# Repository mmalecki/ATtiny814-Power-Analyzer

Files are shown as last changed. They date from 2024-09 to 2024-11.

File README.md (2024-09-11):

# Pocker Power Prowler

**Note: this is still very much a work in progress, and next version will bring considerable improvements over the current one.**

Pocket Power Prowler is a tiny programmable constant current dummy load with voltage and current sensors for test device's power supply, as well as its output under test.

It is programmable via USB using a simple text-based protocol, and [in the future](https://github.com/mmalecki/Pocket-Power-Prowler/issues/4)), the [SCPI protocol](https://en.wikipedia.org/wiki/Standard_Commands_for_Programmable_Instruments).

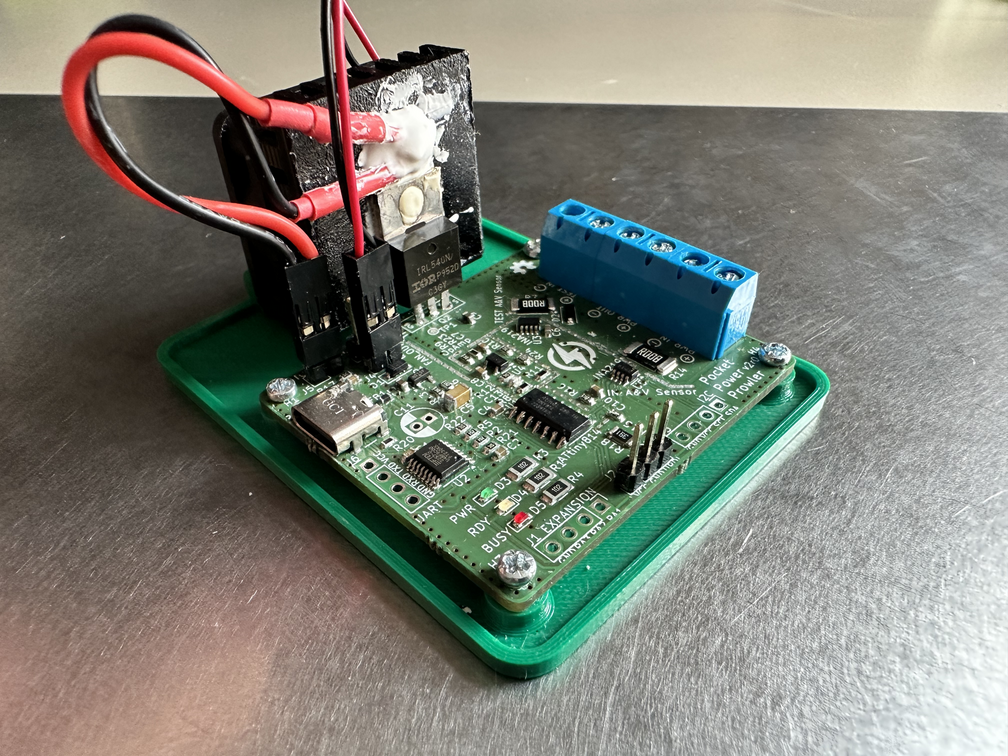
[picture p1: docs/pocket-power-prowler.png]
Pocket Power Prowler picture


It is based on the [ATtiny814 Power Analyzer](https://github.com/wagiminator/ATtiny814-Power-Analyzer) by [@wagiminator](https://github.com/wagiminator/ATtiny814-Power-Analyzer).
If you're interested in how the project changed, check out the [changelog](CHANGELOG.md).

The overarching goal of the project is to create a portable, accurate, reliable and safe dummy load.

# Current control
Current control is implemented using the ATtiny814's digital-to-analog converter (DAC), a level-shifting operational amplifier
(OpAmp) as well as [INA219](https://www.ti.com/lit/ds/symlink/ina219.pdf) current sensor connected to a 8mΩ shunt resistor.

While running a test, software on the ATtiny constantly compares the desired current set by user with current reported by
the sensor, and makes adjustments to the DAC output as necessary, in turn controlling the gate voltage of a
[IRL540N](https://datasheet.lcsc.com/lcsc/1808281632_Infineon-Technologies-IRL540NPBF_C111607.pdf) logic level
power MOSFET, which adjusts its resistance, therefore changing the current flowing and being dissipated through it.

## DAC and OpAmp
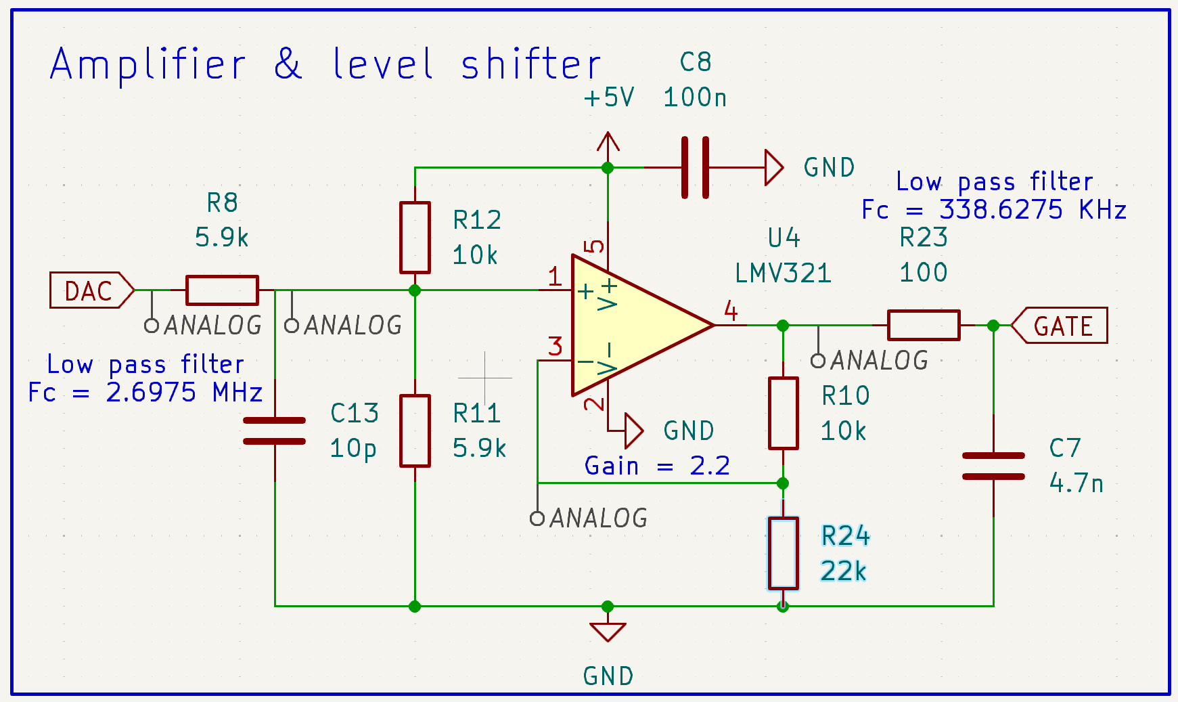
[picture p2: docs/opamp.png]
Digital-to-analog converter output connected to level-shifting and amplifying operational amplifier


The resistor values (for gain and voltage offset) were picked so that when ATtiny outputs 0 V on its DAC output,
the voltage at the gate of MOSFET is just below its turning on point (V<sub>GS</sub>), and when ATtiny outputs the full
DAC voltage at our picked reference point (1.5 V), the MOSFET is conducting the full amount of current we're
equipped to handle (5 A). In short, we're looking for the (almost entire) range of the DAC to cover the (almost entire)
ohmic region of the MOSFET.

## Current sensor and current control loop
On a set interval (currently 5 ms), the ATtiny reads current levels from the load-side INA219 sensor, compares them to set value
and reacts accordingly if the current differs from the setpoint.

This is necessary due to inherently nonlinear characteristics of any MOSFET, changing with voltages, currents and temperatures affecting it.

## Compiling and Uploading the Firmware

### If using the makefile (Linux/Mac)
- Connect your [programmer](https://github.com/wagiminator/AVR-Programmer) (jtag2updi or SerialUPDI) to your PC and to the UPDI header on the board.
- Make sure you have installed the latest [avr-gcc toolchain](http://maxembedded.com/2015/06/setting-up-avr-gcc-toolchain-on-linux-and-mac-os-x/).
- Open a terminal.
- Navigate to the folder with the makefile and the sketch.
- Run `DEVICE=attiny814 PROGRMR=serialupdi PORT=/dev/ttyUSB0 make install` to compile, burn the fuses and upload the firmware (change DEVICE, PROGRMR and PORT accordingly).

# Operating Instructions
The device can be operated in two ways:
- Using a serial monitor: Test algorithms can be started by sending the corresponding command via a serial monitor. The collected data will be displayed in the serial monitor and can be exported to a spread sheet program for further analysis.
- Using the [web app](...). This is the easy way. Everything should be self-explanatory. All following example pictures are created by this application.

## **Load Test**

- Command: "l  *maxloadcurrent[mA: 0..5000]* *minloadvoltage[mV: 0..26000]*"
- Example: "l 2500 4200"
- Prowler continuously increases the load from 0 mA up to *maxloadcurrent*. It stops automatically if the voltage drops below *minloadvoltage*. It continuously transmits the measured values via the serial interface in the format: `current[mA] voltage[mV] power[mW]` (seperated by the `SEPERATOR` character).



## **Voltage Regulation Test**

- Command: "g *maxloadcurrent[mA: 17..5000]*"
- Example: "g 3000"
- The Power Analyzer changes rapidly the load between 17 mA and *maxloadcurrent*. It continuously transmits the measured values via the serial interface in the format: time[ms] current[mA] voltage[mV] (seperated by the SEPERATOR string).



## **Efficiency Test**

- Command: "e  *maxloadcurrent[mA: 17..5000]* *minloadvoltage[mV: 0..26000]*"
- Example: "e 4000 2500"
- The Power Analyzer continuously increases the load from 17 mA up to *maxloadcurrent*. It stops automatically if the voltage at TEST-IN drops below *minloadvoltage*. It continuously transmits the measured values via the serial interface in the format: current[mA] voltage[mV] efficiency[% * 10] (seperated by the SEPERATOR string).



## **Battery Discharge Test**

- Command: "b  *maxloadcurrent[mA: 17..5000]* *minloadvoltage[mV: 0..26000]*"
- Example: "l 1000 2700"
- The Power Analyzer sets a constant current load of *maxloadcurrent*. If the voltage drops below *minloadvoltage* it constantly decreases the load to maintain *minloadvoltage*. It stops automatically if the load current drops to 0mA. It continuously transmits the measured values via the serial interface in the format: time[s] current[mA] voltage[mV] capacity[mAh] (seperated by the SEPERATOR string).



## **Long-Term Multimeter**

- Command: "m  *interval[ms: 2..65535]* *duration[s: 1..65535]*"
- Example: "m 18000 18000"
- The Power Analyzer measures voltage, current and power delivered to the test device at every *interval* for a total of *duration*. It continuously transmits the measured values via the serial interface in the format: time[ms] current[mA] voltage[mV] (seperated by the SEPERATOR string).



## **Commands for Direct Control**
|Command|Function|
|-|-|
|"i"|transmits indentification string ("Power Analyzer")|
|"v"|transmits firmware version number|
|"x"|terminate current test program, reset load to minimum|
|"s *loadcurrent[mA]*"|set load to a constant current of *loadcurrent*|
|"t"|read current and voltage of both sensors and transmit them|

# Notes
- Use a good heatsink with a fan for the MOSFET! Attach a 10K 3977B or 3950B (configurable in code) NTC thermistor to the heatsink close to the MOSFET!
- Be careful with high power loads! Make some tests to figure out what can be achieved with your cooling solution!
- The maximum load current is 5A, however for small voltages it might be less.
- The maximum PWR-IN/PWR-OUT current is 8A.
- Do not exceed the maximum voltage of 26V on all connectors!
- In order to make the design much simpler all connectors including USB share a common ground. Keep this in mind when making your test setup in order to avoid ground loops or shorts. Using a [USB isolator](https://github.com/wagiminator/ADuM3160-USB-Isolator) between the Analyzer and your PC is not a bad idea!
- You need a UPDI programmer for uploading the firmware. You can find one in my [projects](https://github.com/wagiminator/AVR-Programmer) or you can easily build one following this [guide](https://github.com/SpenceKonde/AVR-Guidance/blob/master/UPDI/jtag2updi.md).

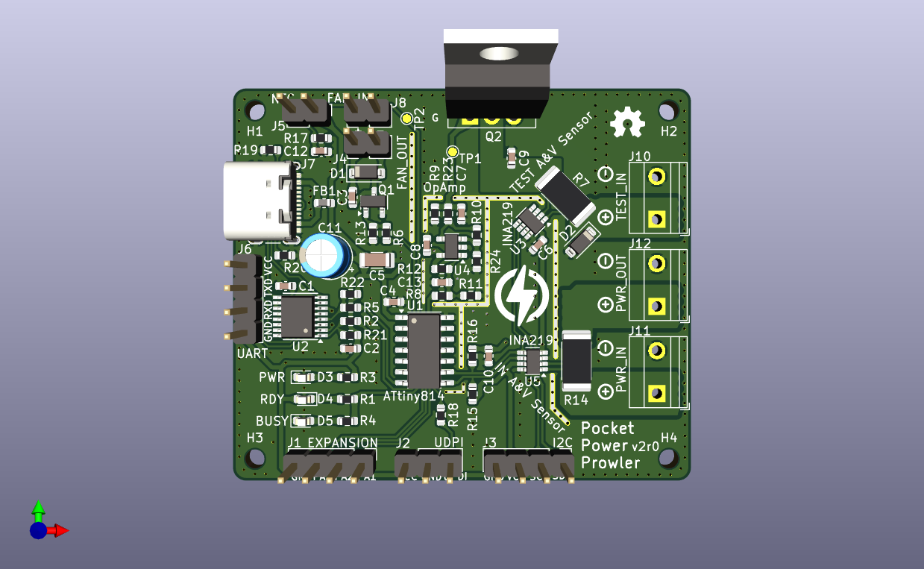
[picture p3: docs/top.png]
Render of the PCB from the top


# License


This work is licensed under Creative Commons Attribution-ShareAlike 3.0 Unported License. 
(http://creativecommons.org/licenses/by-sa/3.0/)

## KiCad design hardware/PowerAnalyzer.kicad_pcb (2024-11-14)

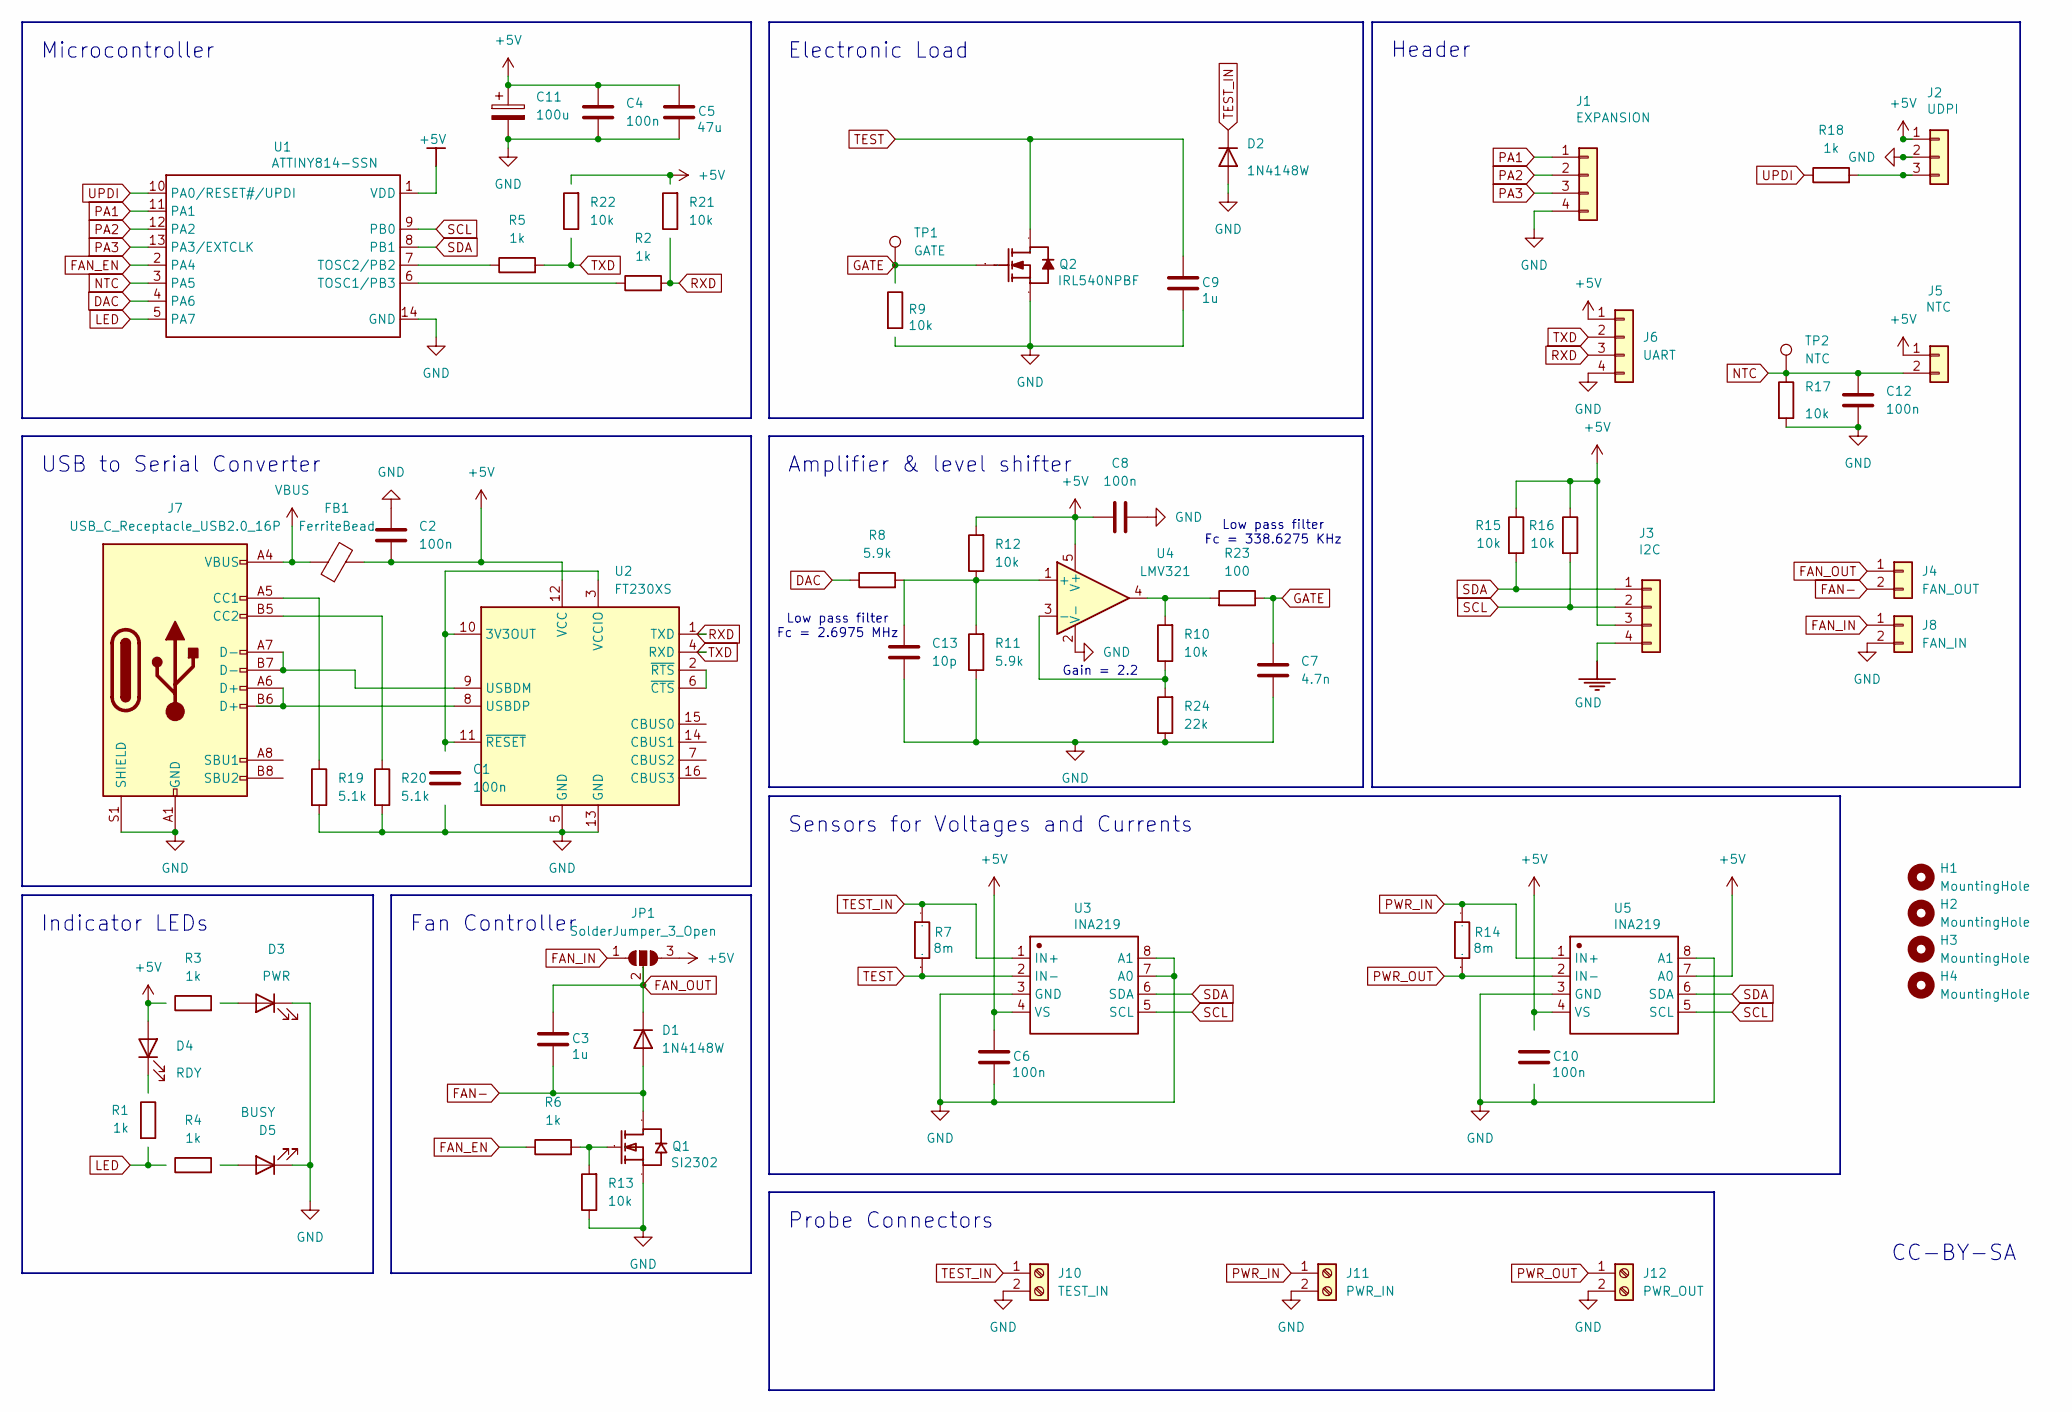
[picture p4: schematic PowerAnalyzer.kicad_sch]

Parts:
C1, C2, C4, C6, C8, C10, C12: 100n; C_0603_1608Metric; Manufacturer Part CC0603KRX7R9BB104
C3, C9: 1u; C_0603_1608Metric; Voltage 50V; Manufacturer Part CL10A105KB8NNNC
C5: 47u; C_1206_3216Metric; Manufacturer Part 1206F476M160NT
C7: 4.7n; C_0603_1608Metric
C11: 100u; CP_Radial_D5.0mm_P2.00mm
C13: 10p; C_0603_1608Metric
D1, D2: 1N4148W; D_SOD-123; Manufacturer Part 1N4148W-E3-08
D3: PWR; LED_0603_1608Metric; Manufacturer Part 19-217/BHC-ZL1M2RY/3T
D4: RDY; LED_0603_1608Metric; Manufacturer Part 19-217/BHC-ZL1M2RY/3T
D5: BUSY; LED_0603_1608Metric; Manufacturer Part 19-217/BHC-ZL1M2RY/3T
FB1: FerriteBead; L_0603_1608Metric; Manufacturer Part BLM18EG121SN1D
H1, H2, H3, H4: MountingHole; MountingHole_2.2mm_M2
J1: EXPANSION; PinHeader_1x04_P2.54mm_Vertical; Manufacturer Part 220S-1*4P H=8.5MM Ytype Gold-plated
J2: UDPI; PinHeader_1x03_P2.54mm_Vertical; Manufacturer Part Header2.54mm 1*3P
J3: I2C; PinHeader_1x04_P2.54mm_Vertical; Manufacturer Part 220S-1*4P H=8.5MM Ytype Gold-plated
J4: FAN_OUT; PinHeader_1x02_P2.54mm_Vertical
J5: NTC; PinHeader_1x02_P2.54mm_Vertical; Manufacturer Part 826629-2
J6: UART; PinHeader_1x04_P2.54mm_Vertical
J7: USB_C_Receptacle_USB2.0_16P; USB_C_Receptacle_GCT_USB4105-xx-A_16P_TopMnt_Horizontal
J8: FAN_IN; PinHeader_1x02_P2.54mm_Vertical
J10: TEST_IN; TerminalBlock_Xinya_XY301V-5.00-2P_1x02_P5.00mm_Horizontal; Manufacturer Part KF301R-5.0-2P
J11: PWR_IN; TerminalBlock_Xinya_XY301V-5.00-2P_1x02_P5.00mm_Horizontal; Manufacturer Part KF301R-5.0-2P
J12: PWR_OUT; TerminalBlock_Xinya_XY301V-5.00-2P_1x02_P5.00mm_Horizontal; Manufacturer Part KF301R-5.0-2P
JP1: SolderJumper_3_Open; SolderJumper-3_P1.3mm_Open_RoundedPad1.0x1.5mm
Q1: SI2302; SOT-23-3; Manufacturer Part SI2302
Q2: IRL540NPBF; TO-220-3_Vertical; Manufacturer Part IRL540NPBF
R1, R2, R3, R4, R5, R6: 1k; R_0603_1608Metric; Manufacturer Part 0603WAF1001T5E
R7, R14: 8m; R_2512_6332Metric; Manufacturer Part MRF6432(2512)LR008FTS
R8: 5.9k; R_0603_1608Metric
R9, R10, R12, R17, R21, R22: 10k; R_0603_1608Metric; Manufacturer Part 0603WAF1002T5E
R11: 5.9k; R_0603_1608Metric; Manufacturer Part 0603WAF1002T5E
R13: 10k; R_0603_1608Metric; Manufacturer Part 0603WAF1001T5E
R15, R16: 10k; R_0603_1608Metric; Manufacturer Part 0603WAF4701T5E
R18: 1k; R_0603_1608Metric; Manufacturer Part 0603WAF4701T5E
R19, R20: 5.1k; R_0603_1608Metric
R23: 100; R_0603_1608Metric
R24: 22k; R_0603_1608Metric
TP1: GATE; TestPoint_Pad_D1.0mm
TP2: NTC; TestPoint_Pad_D1.0mm
U1: ATTINY814-SSN; SOIC-14_3.9x8.7mm_P1.27mm; Manufacturer Part ATTINY814-SSNR
U2: FT230XS; SSOP-16_3.9x4.9mm_P0.635mm
U3, U5: INA219; SOT-23-8; Manufacturer Part INA219AIDCNR
U4: LMV321; SOT-23-5

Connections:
+5V: C2.1, C4.1, C5.1, C6.1, C8.1, C10.1, C11.1, D4.2 (A), FB1.2, J2.1, J3.3, J5.1, J6.1, JP1.3 (B), R3.1, R12.2, R15.1, R16.1, R21.2, R22.2, U1.1 (VDD), U2.12 (VCC), U3.4 (VS), U4.5 (V+), U5.4 (VS), U5.7 (A0)
DAC: R8.1, U1.4 (PA6)
FAN-: C3.2, D1.2 (A), J4.2, Q1.3 (D)
FAN_EN: R6.1, U1.2 (PA4)
FAN_IN: J8.1, JP1.1 (A)
FAN_OUT: C3.1, D1.1 (K), J4.1, JP1.2 (C)
GATE: C7.1, Q2.1 (G), R9.1, R23.1, TP1.1
GND: C1.1, C2.2, C4.2, C5.2, C6.2, C7.2, C8.2, C9.2, C10.2, C11.2, C12.1, C13.2, D2.2 (A), D3.1 (K), D5.1 (K), J1.4, J2.2, J3.4, J6.4, J7.A1 (GND), J7.A12 (GND), J7.B1 (GND), J7.B12 (GND), J7.S1 (SHIELD), J8.2, J10.2, J11.2, J12.2, Q1.2 (S), Q2.3 (S), R9.2, R11.1, R13.1, R17.2, R19.2, R20.2, R24.1, U1.14 (GND), U2.5 (GND), U2.13 (GND), U3.3 (GND), U3.7 (A0), U3.8 (A1), U4.2 (V-), U5.3 (GND), U5.8 (A1)
LED: R1.2, R4.1, U1.5 (PA7)
NTC: C12.2, J5.2, R17.1, TP2.1, U1.3 (PA5)
unnamed: D3.2 (A), R3.2
unnamed: D4.1 (K), R1.1
unnamed: D5.2 (A), R4.2
unnamed: J2.3, R18.2
unnamed: J7.A5 (CC1), R19.1
unnamed: J7.B5 (CC2), R20.1
unnamed: Q1.1 (G), R6.2, R13.2
unnamed: R10.2, R23.2, U4.4
unnamed: R2.1, U1.6 (TOSC1/PB3)
unnamed: R5.1, U1.7 (TOSC2/PB2)
unnamed: J7.A7 (D-), J7.B7 (D-), U2.9 (USBDM)
unnamed: J7.A6 (D+), J7.B6 (D+), U2.8 (USBDP)
unnamed: U2.2 (~RTS), U2.6 (~CTS)
unnamed: C13.1, R8.2, R11.2, R12.1, U4.1 (+)
unnamed: R10.1, R24.2, U4.3 (-)
PA1: J1.1, U1.11 (PA1)
PA2: J1.2, U1.12 (PA2)
PA3: J1.3, U1.13 (PA3/EXTCLK)
PWR_IN: J11.1, R14.2, U5.1 (IN+)
PWR_OUT: J12.1, R14.1, U5.2 (IN-)
RXD: J6.3, R2.2, R21.1, U2.1 (TXD)
SCL: J3.2, R16.2, U1.9 (PB0), U3.5 (SCL), U5.5 (SCL)
SDA: J3.1, R15.2, U1.8 (PB1), U3.6 (SDA), U5.6 (SDA)
TEST: C9.1, Q2.2 (D), R7.1, U3.2 (IN-)
TEST_IN: D2.1 (K), J10.1, R7.2, U3.1 (IN+)
TXD: J6.2, R5.2, R22.1, U2.4 (RXD)
UPDI: R18.1, U1.10 (PA0/RESET#/UPDI)
VBUS: FB1.1, J7.A4 (VBUS), J7.A9 (VBUS), J7.B4 (VBUS), J7.B9 (VBUS)

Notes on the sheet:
USB to Serial Converter
Sensors for Voltages and Currents
Indicator LEDs
Header
Gain = 2.2
Microcontroller
CC-BY-SA
Low pass filter Fc = 338.6275 KHz
Amplifier & level shifter
Electronic Load
Low pass filter Fc = 2.6975 MHz
Fan Controller
Probe Connectors

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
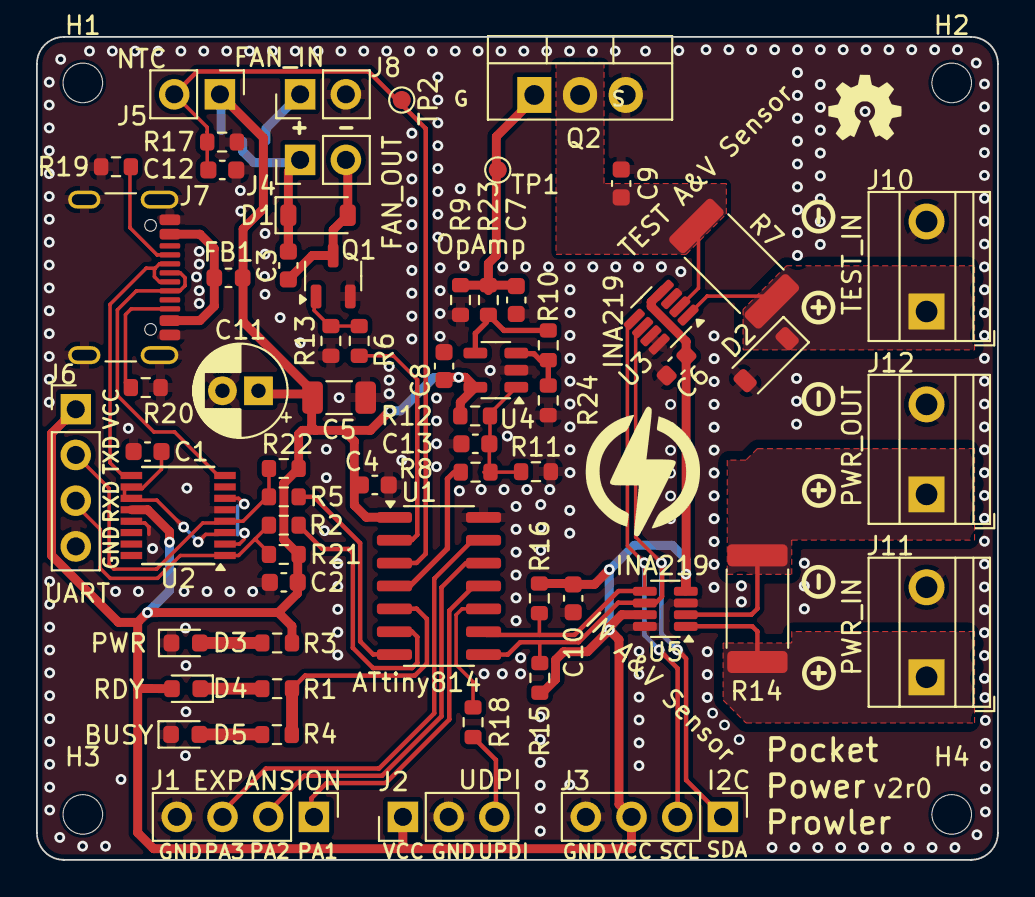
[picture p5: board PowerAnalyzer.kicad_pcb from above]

Board: 2 copper layers, 53.4 x 45.7 mm, 68 parts (1 on the bottom side), 39 nets.

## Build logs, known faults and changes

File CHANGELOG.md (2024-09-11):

# v2r0

## Hardware

### Direct current control loop as opposed to shunt-based method
In order to save board space and reduce heat transfer concerns to
a single element (the MOSFET), direct current control from ATtiny
was used instead the constant current source method with an opamp
and shunt resistor.
This also ensures a single source of truth for both measurement and
current control.

### Other
* Migrated to KiCad
* Migrate from USB B to USB C
* Migrate from CH330N to FT232 due to part availability
* Drastically reduce DAC output capacitor, change its purpose from seemingly sampling to filtering, removing seesaw effect (max allowed capacitance is 30 pF)
* Add a low-pass RC filter on both input and output of the opamp
* Move OpAmp closer to DAC, reducing noise pick up
* Add sampling capacitor to NTC
* Add ferrite bead to USB power

## Software
* Add direct NTC probe temperature calculations
* Refactor to control-loop-based current control
* Implement overload notification
* Start using the LED for error and status notifications (various blinks)
* Implement reporting and adjusting of programs at different intervals
* General clean-up
* Bundle multimeter (`m`) and transmit sensors (`t`) into one, with optional timing info
* Add some debug commands
* Change `SEPARATOR` to character

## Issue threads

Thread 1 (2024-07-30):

Move to PI controller for current control

mmalecki, 2024-07-30:
Current circuit and firmware uses pre-estabilished DAC values to control the MOSFET gate. This, however, doesn't account for thermals, slightly different characteristics with different input voltages, etc.

We should implement INA219 feedback-based current control, actuated via DAC directly, no shunt.

Closed 2024-08-23.

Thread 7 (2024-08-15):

Better MOSFET... situation?

mmalecki, 2024-08-15:
We should probably pick a transistor better suited to ohmic region operation, such as IXTT80N20L.
Also consider mounting it on a separate, sandwiched board for ease of replacement should something go wrong.

mmalecki, 2024-12-03:
IXTK44N50L appears to have a nice-looking admittance vs Vgs graph as well

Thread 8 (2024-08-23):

Off-board DAC

mmalecki, 2024-08-23:
Currently we have 12 bits on the sensor inputs, but 8 bits of DAC precision on the way out, which is an incredibly tasty recipe for controller instability and general shitness. We should pick an off-board DAC, preferably 12 bit (or ref #6 and get more bits).

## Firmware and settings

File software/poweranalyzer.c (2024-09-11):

// ===================================================================================
// Project:   Power Analyzer
// Version:   1.1
// Year:      2020
// Author:    Stefan Wagner
// Github:    https://github.com/wagiminator
// EasyEDA:   https://easyeda.com/wagiminator
// License:   http://creativecommons.org/licenses/by-sa/3.0/
// ===================================================================================
//
// Description:
// ------------
// Programmable electronic constant current dummy load with two high side voltage
// and current sensors for an automatic analysis of power supplys, DC/DC converters,
// voltage regulators, batteries, chargers, power consumers and others.
// The device can be controlled via USB serial interface using a serial monitor or
// the provided python skripts. Data can be exported to spread sheet programs or
// directly be analyzed by the python skripts.
//
// Wiring:
// -------
//                            +-\/-+
//                      Vcc  1|°   |14  GND
//     Fan --- !SS AIN4 PA4  2|    |13  PA3 AIN3 SCK ---- 
//     NTC ------- AIN5 PA5  3|    |12  PA2 AIN2 MISO --- 
//    Load --- DAC AIN6 PA6  4|    |11  PA1 AIN1 MOSI --- 
//     LED ------- AIN7 PA7  5|    |10  PA0 AIN0 UPDI --- UPDI
//     USB -------- RXD PB3  6|    |9   PB0 AIN11 SCL --- INA219
//     USB ---------TXD PB2  7|    |8   PB1 AIN10 SDA --- INA219
//                            +----+
//
// Compilation Settings:
// ---------------------
// Core:    megaTinyCore (https://github.com/SpenceKonde/megaTinyCore)
// Board:   ATtiny1614/1604/814/804/414/404/214/204
// Chip:    ATtiny1614 or ATtiny814
// Clock:   20 MHz internal
//
// Leave the rest on default settings. Don't forget to "Burn bootloader"!
// Compile and upload the code.
//
// No Arduino core functions or libraries are used. To compile and upload without
// Arduino IDE download AVR 8-bit toolchain at:
// https://www.microchip.com/mplab/avr-support/avr-and-arm-toolchains-c-compilers
// and extract to tools/avr-gcc. Use the makefile to compile and upload.
//
// Fuse Settings: 0:0x00 1:0x00 2:0x02 4:0x00 5:0xC5 6:0x04 7:0x00 8:0x00
//
// ===================================================================================
// Operating Instructions
// ===================================================================================
// Load Test:
//
// TEST-IN <---- Test Power Supply
// PWR-OUT --X-- unconnected
// PWR-IN  --X-- unconnected
//
// Command: "l <maxloadcurrent[mA: 17..5000]> <minloadvoltage[mV: 0..26000]>"
// Example: "l 1000 2900"
// The Power Analyzer continuously increases the load from 17 mA up to <maxloadcurrent>.
// It stops automatically if the voltage drops below <minloadvoltage>. It continuously
// transmits the measured values via the serial interface in the format: 
// current[mA] voltage[mV] power[mW] (seperated by the SEPERATOR string).
// ---------------------------------------------------------------------------------------
// Voltage Regulation Test:
//
// TEST-IN <---- Test Power Supply
// PWR-OUT --X-- unconnected
// PWR-IN  --X-- unconnected
//
// Command: "g <maxloadcurrent[mA: 17..5000]>"
// Example: "g 3000"
// The Power Analyzer changes rapidly the load between 17 mA and <maxloadcurrent>.
// It continuously transmits the measured values via the serial interface in the format: 
// time[ms] current[mA] voltage[mV] (seperated by the SEPERATOR string).
// ---------------------------------------------------------------------------------------
// Efficiency Test:
//
// TEST-IN <---- DC/DC Converter Output
// PWR-OUT ----> DC/DC Converter Input
// PWR-IN  <---- Power Source
//
// Command: "e <maxloadcurrent[mA: 17..5000]> <minloadvoltage[mV: 0..26000]>"
// Example: "e 1000 4700"
// The Power Analyzer continuously increases the load from 17 mA up to <maxloadcurrent>.
// It stops automatically if the voltage at TEST-IN drops below <minloadvoltage>. It 
// continuously transmits the measured values via the serial interface in the format: 
// current[mA] voltage[mV] efficiency[% * 10] (seperated by the SEPERATOR string).
// ---------------------------------------------------------------------------------------
// Low Frequency Ripple Test:
//
// TEST-IN <---- Test Power Supply
// PWR-OUT --X-- unconnected
// PWR-IN  --X-- unconnected
//
// Command: "f <maxloadcurrent[mA: 17..5000]> <minloadvoltage[mV: 0..26000]>"
// Example: "f 1000 4700"
// The Power Analyzer continuously increases the load from 17 mA up to <maxloadcurrent>.
// It stops automatically if the voltage at TEST-IN drops below <minloadvoltage>. It 
// continuously transmits the measured values via the serial interface in the format: 
// current[mA] peak-to-peak voltage[mV] (seperated by the SEPERATOR string).
// ---------------------------------------------------------------------------------------
// Battery Discharge Test:
//
// TEST-IN <---- Battery
// PWR-OUT --X-- unconnected
// PWR-IN  --X-- unconnected
//
// Command: "b <maxloadcurrent[mA: 17..5000]> <minloadvoltage[mV: 0..26000]>"
// Example: "l 1000 2900"
// The Power Analyzer sets a constant current load of <maxloadcurrent>. If the voltage
// drops below <minloadvoltage> it constantly decreases the load to maintain
// <minloadvoltage>. It stops automatically if the load current drops to 0mA. It
// continuously transmits the measured values via the serial interface in the format: 
// time[s] current[mA] voltage[mV] capacity[mAh] (seperated by the SEPERATOR string).
// ---------------------------------------------------------------------------------------
// Long-Term Multimeter:
//
// TEST-IN --X-- unconnected
// PWR-OUT ----> Power Consumer
// PWR-IN  <---- Power Source
//
// Command: "m <interval[ms: 2..65535]> <duration[s: 1..65535]>"
// Example: "m 1000 600"
// The Power Analyzer measures voltage, current and power delivered to the test device at
// every <interval> for a total of <duration>. It continuously transmits the measured
// values via the serial interface in the format: 
// time[ms] current[mA] voltage[mV] (seperated by the SEPERATOR string).
// ---------------------------------------------------------------------------------------
// Calibration:
//
// Set all calibration values in the sketch to 1, compile and upload.
// Connect a power supply to PWR-IN and connect PWR-OUT to TEST-IN with an ammeter in 
// between the positive line. Connect the voltmeter to the TEST-IN terminals. Make sure
// not to exceed the maximum load power.
//
// TEST-IN <---- |Multi-
// PWR-OUT ----> |meter
// PWR-IN  <---- Power Source
//
// Command: "c <loadcurrent[mA: 17..5000]> <duration[s: 1..65535]>"
// Example: "c 1000 10"
// The Power Analyzer sets a constant current load of <loadcurrent> for <duration>.
// It averages the measurements if both voltage/current sensors and transmits the
// values via the serial interface in the format: 
// current_load[mA] voltage_load[mV] current_power[mA] voltage_power[mV] (seperated by the SEPERATOR string)
// Measure voltage and current with a trusty multimeter during this time and calculate
// the calibration values as follows:
// ILCAL1 = current measured with multimeter / transmitted value of current_load
// ULCAL1 = voltage measured with multimeter / transmitted value of voltage_load
// ILCAL2 = current measured with multimeter / transmitted value of current_power
// ULCAL2 = voltage measured with multimeter / transmitted value of voltage_power
// Change the calibration values in the sketch, compile and upload.
// ---------------------------------------------------------------------------------------
// Commands for Direct Control:
//
// Command                Function
// "i"                    transmit indentification string ("Power Analyzer")
// "v"                    transmit firmware version number
// "x"                    terminate current test program
// "s <loadcurrent[mA]>"  set load to a constant current of <loadcurrent>
// "p <loadpower [mW]>"   set load to a constant power of <loadpower> (not yet implemented)
// "o <resistance [Ohm]>" set load to a constant resistance of <resistance> (nyi)
// "r"                    reset the load to minimum
// "t"                    read current and voltage of both sensors and transmit them
// ---------------------------------------------------------------------------------------
// Notes:
// - Use a good heatsink with a 5V fan for the MOSFET!
// - Be careful with high power loads! Make some tests to figure out what can be achieved
//   with your cooling solution!
// - Due to the limitations of the OpAmp the minimum load current is around 17mA.
//   You can choose a better OpAmp if you like, but for most cases this is not neccessary.
// - The maximum load current is 5A, however for small voltages it might be less.
// - The maximum PWR-IN/PWR-OUT current is 8A.
// - Do not exceed the maximum voltage of 26V on all connectors !
// - In order to make the design much simpler all connectors including USB have a common
//   ground. Keep this in mind when making your test setup in order to avoid ground loops
//   or shorts. Using a USB isolator between the Analyzer and your PC is not a bad idea!  


// ===================================================================================
// Libraries, Definitions and Macros
// ===================================================================================

// Libraries
#include <avr/io.h>                     // for GPIO
#include <avr/interrupt.h>              // for interrupts
#include <util/delay.h>                 // for delays
#include <string.h>
#include <math.h>
#include <stdlib.h>

// Pin definitions
#define FAN_PIN     PA4                 // pin the fan is connected to
#define NTC_PIN     PA5                 // pin the temperature sensor is connected to
#define DAC_PIN     PA6                 // DAC output pin, connected to load
#define LED_PIN     PA7                 // pin the status LED is connected to
#define SCL_PIN     PB0                 // I2C serial clock pin, connected to INA219
#define SDA_PIN     PB1                 // I2C serial data pin, connected to INA219
#define TXD_PIN     PB2                 // UART transmit data pin, connected to CH330N
#define RXD_PIN     PB3                 // UART receive data pin, connected to CH330N

// Identifiers
#define VERSION     "2.0"               // version number sent via serial if requested
#define IDENT       "Power Analyzer"    // identifier sent via serial if requested
#define SEPARATOR   '\t'                // seperator string for serial communication
#define DONE        "DONE"              // string sent when operation has finished
#define ERROR       "ERROR"
#define OVERLOAD    "OVERLOAD"

// Calibration values
#define ILCAL1      1                   // linear current calibration factor (load)
#define ULCAL1      1                   // linear voltage calibration factor (load)
#define ILCAL2      1                   // linear current calibration factor (supply)
#define ULCAL2      1                   // linear voltage calibration factor (supply)

// Parameters

// XXX(mmalecki): we're rated to 5 A and technically could do much, much more, given
// an appropriate cooling solution. However, INA219's maximum sense voltage and the
// current shunt resistors in place limit our capabilities.
// We could set a divider (PGA) on INA side, or change out the resistors. For the
// time being, however, limit the maximum current to a unit under, so the controller
// is able to operate.
#define MAXCURRENT  4999
#define MAXPOWER    25000               // maximum power of the load in mW -> turn off load

#define FANONPOWER  700                 // power in mW to turn fan on
#define FANOFFPOWER 500                 // power in mW to turn fan off
#define MAXTEMP     85                  // max temperature
#define FANONTEMP   50                  // fan-on temperature
#define FANOFFTEMP  45                  // fan-off temperature

#undef CONTROLLER_DEBUG

#define DAC_MIN 0
#define DAC_MAX 255

#define DAC_LOW_CURRENT_P   0.075
#define DAC_LOW_CURRENT     1000
#define DAC_HIGH_CURRENT_P  0.05

/* #define DAC_MAX_CURRENT 7500 */
#define DAC_MAX_CHANGE 20.0

// NTC probe
#define _K 273.15
#define C_TO_K(X) (X + 273.15)
#define K_TO_C(X) (X - 273.15)

#define NTC_BETA    3977.0
#define NTC_R0      10000.0
#define NTC_T0      C_TO_K(25.0) // reference temperature [K]
#define NTC_DIV_R1  10000.0
#define ADC_MAX     1023.0

#define STEP        50    // control loop time step, ms

#define ADJ_STEP    500  // adjustment step, ms: how often to adjust current in test programs
#define CURRENT_ADJ 10

#define REPORT_STEP 50  // report time step, ms: how often to report

#define BLINK_SHORT_INFO  250
#define BLINK_INFO        500
#define BLINK_ERROR       1250

// INA219 register values
#define INA1ADDR    0b10000000          // I2C write address of INA on the load side 
#define INA2ADDR    0b10000010          // I2C write address of INA on the power side

#define INA1CONFIG  0b0010101001100111  // INA config register according to datasheet
#define INA2CONFIG  0b0010111001100111  // INA config register according to datasheet
#define INAFASTBUS  0b0010110001000110  // INA config register according to datasheet
#define INAFASTBOTH 0b0010110001000111  // INA config register according to datasheet
#define INACALIB    5120                // INA calibration register according to R_SHUNT
#define CONFIG_REG  0x00                // INA configuration register address
#define CALIB_REG   0x05                // INA calibration register address
#define SHUNT_REG   0x01                // INA shunt voltage register address
#define VOLTAGE_REG 0x02                // INA bus voltage register address
#define POWER_REG   0x03                // INA power register address
#define CURRENT_REG 0x04                // INA current register address

// Pin manipulation macros
enum {PA0, PA1, PA2, PA3, PA4, PA5, PA6, PA7, PB0, PB1, PB2, PB3};    // enumerate pin designators
#define pinInput(x)       (&VPORTA.DIR)[((x)&8)>>1] &= ~(1<<((x)&7))  // set pin to INPUT
#define pinOutput(x)      (&VPORTA.DIR)[((x)&8)>>1] |=  (1<<((x)&7))  // set pin to OUTPUT
#define pinLow(x)         (&VPORTA.OUT)[((x)&8)>>1] &= ~(1<<((x)&7))  // set pin to LOW
#define pinHigh(x)        (&VPORTA.OUT)[((x)&8)>>1] |=  (1<<((x)&7))  // set pin to HIGH
#define pinToggle(x)      (&VPORTA.IN )[((x)&8)>>1] |=  (1<<((x)&7))  // TOGGLE pin
#define pinRead(x)        ((&VPORTA.IN)[((x)&8)>>1] &   (1<<((x)&7))) // READ pin
#define pinDisable(x)     (&PORTA.PIN0CTRL)[(((x)&8)<<2)+((x)&7)] |= PORT_ISC_INPUT_DISABLE_gc
#define pinPullup(x)      (&PORTA.PIN0CTRL)[(((x)&8)<<2)+((x)&7)] |= PORT_PULLUPEN_bm
#define pinAIN(x)         ((x)<8 ? (x) : (19-(x)))                    // convert pin to ADC port

#define MAX(a, b)         (a > b ? a : b)
#define MIN(a, b)         (a < b ? a : b)

#define ledBlink(INTERVAL) ledToggle(); \
                           _delay_ms(INTERVAL); \
                           ledToggle(); \
                           _delay_ms(INTERVAL);

#define ledBusy() pinHigh(LED_PIN)
#define ledReady() pinLow(LED_PIN)
#define ledToggle() pinToggle(LED_PIN)

typedef enum { FAN_AUTO, FAN_MANUAL } fan_control_t;
typedef enum { DAC_AUTO, DAC_MANUAL } dac_control_t;

// Global variables (voltages in mV, currents in mA, power in mW, shunts in 0.01 mV)
uint16_t current_desired = 0;
uint16_t voltage_load, current_load, voltage_power, current_power, shunt1, shunt2, power2, loadtemp = 0;

bool query = false;
uint16_t argument1, argument2;
uint16_t loadpower = 0;
char     cmd;

fan_control_t fan_control = FAN_AUTO;
dac_control_t dac_control = DAC_AUTO;

// ===================================================================================
// UART Implementation - Low Level Functions (8N1, no calibration, with RX-interrupt)
// ===================================================================================

// UART definitions and macros
#define UART_BAUD         115200
#define UART_BAUD_RATE    ((float)(F_CPU * 64 / (16 * (float)UART_BAUD)) + 0.5)
#define UART_ready()      (USART0.STATUS & USART_DREIF_bm)

#undef UART_LOOPBACK
#undef UART_DEBUG

// UART init
void UART_init(void) {
  pinInput(RXD_PIN);                              // set RX pin as input
  pinOutput(TXD_PIN);                             // set TX pin as output
  USART0.BAUD   = UART_BAUD_RATE;                 // set BAUD
  USART0.CTRLA  = USART_RXCIE_bm;                 // enable RX interrupt
  USART0.CTRLB  = USART_RXEN_bm                   // enable RX
                | USART_TXEN_bm;                  // enable TX
}

// UART transmit data byte
void UART_write(char data) {
  while(!UART_ready());                           // wait until ready for next data
  USART0.TXDATAL = data;                          // send data byte
}

// ===================================================================================
// UART Implementation - String Functions
// ===================================================================================

// UART print string
void UART_print(const char *str) {
  for (size_t i = 0; i < strlen(str); i++)  { UART_write(str[i]); }
}

// UART print string with new line
void UART_println(const char *str) {
  UART_print(str);                                // print string
  UART_write('\r');                               // send new line command
  UART_write('\n');                               // send new line command
}

// UART print 16-bit integer as decimal (BCD conversion by substraction method)
void UART_printInt(uint16_t value) {
  static uint16_t divider[5] = {10000, 1000, 100, 10, 1};
  uint8_t leadflag = 0;                           // flag for leading spaces
  for(uint8_t digit = 0; digit < 5; digit++) {    // 5 digits
    uint8_t digitval = 0;                         // start with digit value 0
    while(value >= divider[digit]) {              // if current divider fits into the value
      leadflag = 1;                               // end of leading spaces
      digitval++;                                 // increase digit value
      value -= divider[digit];                    // decrease value by divider
    }
    if(leadflag || (digit == 4)) UART_write(digitval + '0'); // print the digit
  }
}

// ===================================================================================
// UART Implementation - Command Buffer
// ===================================================================================

// UART command buffer and pointer
#define CMD_BUF_LEN 16                            // command buffer length
volatile uint8_t CMD_buffer[CMD_BUF_LEN] = { 0 };         // command buffer
volatile uint8_t CMD_ptr = 0;                     // buffer pointer for writing
volatile uint8_t CMD_compl = 0;                   // command completely received flag

void ledError() {
  ledBlink(BLINK_ERROR);
  ledBlink(BLINK_ERROR);
}

// UART RXC interrupt service routine (read command via UART)
ISR(USART0_RXC_vect) {
  uint8_t data = USART0.RXDATAL;                  // read received data byte
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
int main(void) {
  // Setup MCU
  _PROTECTED_WRITE(CLKCTRL.MCLKCTRLB, 0);         // set clock frequency to 20 MHz

  ledBusy();

  // Setup modules
  UART_init();                                    // init UART
  I2C_init();                                     // init I2C
  INA_init();                                     // init INA219
  DAC_init();                                     // init DAC
  ADC_init();                                     // init ADC
  MIL_init();                                     // init millis counter
  sei();                                          // enable interrupts

  // Setup pins
  pinOutput(FAN_PIN);                             // set fan pin as output
  pinOutput(LED_PIN);                             // set LED pin as output

#ifdef NTC_PIN
  pinDisable(NTC_PIN);                            // disable digital input buffer
#endif

  // This delay not necessary, but the reassuring transition isn't visible otherwise:
  _delay_ms(BLINK_INFO);
  ledReady();

  // Loop
  while(1) {
    CMD_read();                                   // wait for and read command
    ledBusy();
    switch(cmd) {
      case 'i':   UART_println(IDENT);   break;   // send identification
      case 'v':   UART_println(VERSION); break;   // send version number
      /* case 'c':   calibrateLoad();       break;   // set load for calibration */
      case 'l':   load_test();           break;   // perform load test
      /* case 'g':   regulationTest();      break;   // perform regulation test */
      /* case 'e':   efficiencyTest();      break;   // perform efficiency test */
      /* case 'r':   ripple_test();          break;   // perform ripple test */
      /* case 'b':   batteryTest();         break;   // perform battery test */
      /* case 'm':   multimeter();          break;   // long-term multimeter */
      case 't':   transmit_sensors();     break;   // read and transmit sensor values
      case 'x':   set_current(0);                // reset the load
                  UART_println(DONE);    break;
      case 's':   set_current(argument1);        // set load current
                  UART_println(DONE);    break; 
      case 'd':
        if (query) {
          UART_printInt(DAC0.DATA);
          UART_println("");
        } else {
          DAC0.DATA = argument1;
          dac_control = DAC_MANUAL;
        }
        break;
      case 'p':   transmit_temperature(); break;   // transmit NTC temp
      case 'w':   set_fan(); break;
      default:    ledError(); CMD_ptr = 0; break;
    }
    ledReady();
  }
}

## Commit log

2024-07-07 Remove old output files
    [PowerAnalyzer_BOM_v1.0.tsv]
2024-07-07 Add a KiCad .gitignore
2024-07-07 Import to KiCad, migrate to USB C
    Stitch some vias.
    Use a FT230, expose UART for use with external converters (e.g.
    Flipper).
    [PowerAnalyzer.kicad_pcb, PowerAnalyzer.kicad_sch]
2024-07-28 Fix diodes
    Their pins are numbered differently on easyEDA.
    Move some vias which may cause tombstoning.
    [PowerAnalyzer.kicad_pcb, PowerAnalyzer.kicad_sch]
2024-07-28 Use stock tools
    Switch to `avrdude` by default, as `pymcuprog` did not work for me.
2024-07-28 Make LED management a little easier
2024-07-28 Implement UART loopback and debug facilities
    Further separator changes.
2024-07-28 Start refactoring temperature handling
    Approximate the NTC temperature using its Beta coefficient.
    Start implementing centralized logic for over-heating and -power.
2024-07-30 Improve thermal behavior
    Calculate temperature based on NTC Beta value.
    Allow turning fans on and off manually, as well as automatically.
    Handle overload while refreshing load sensors instead of in every test
    function separately. This saves us sizable flash space.
    Have 'x' reset load in the menu.
    [poweranalyzer.c]
2024-07-31 Pocket Power Prowler v2
    Migrate from semi-constant current control via shunt and operational
    amplifier to direct DAC- and P[ID]-based control algorithm.
    Bias the op amp just below the MOSFET threshold voltage to make use of
    full DAC range.
    Reduce DAC output capacitance from 100 n to 10 p (in order to filter out
    high frequencies coming from DAC peripheral clock).
    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
    [PowerAnalyzer.kicad_pcb, PowerAnalyzer.kicad_sch]
2024-08-10 Allow disabling NTC for testing purposes
    Otherwise we're just spewing infinite OVERLOAD messages due to the
    sensor having infinite resistance if unplugged.
2024-08-10 Finish (?) KiCadifying
    [PowerAnalyzer.kicad_pcb, PowerAnalyzer.kicad_sch]
2024-08-12 Implement incredibly basic error correction based on current reading
    Remove the multimeter (`m`) command and add optional time parameters to
    transmit sensors (`s`).
    [poweranalyzer.c]
2024-08-12 Use tried and tested values
    Rework on that opamp section sure was fun.
    [PowerAnalyzer.kicad_sch]
2024-08-12 Move the transistor a bit to the right
    Allow more space for the heatsink.
    [PowerAnalyzer.kicad_pcb]
2024-08-13 Disable UART echoback by default
2024-08-13 Limit maximum current to 4999 mA
2024-08-15 Increase the range of load-side INA219 current sensor
2024-09-11 Add a v2r0 case
2024-09-11 More documentation in the schematic
    [PowerAnalyzer.kicad_sch]
2024-09-11 Output PCB step file for case visualizations
2024-09-11 Describe reasoning behind current control changes
2024-09-11 Add the opamp simulation project
    [opamp-simulation.kicad_pcb, opamp-simulation.kicad_sch]
2024-09-11 Pocket Power Prowler!
2024-09-11 Mount the new cooling solution
2024-09-11 Remove the `DRCError` layer
    [PowerAnalyzer.kicad_pcb]
2024-11-14 Fix layer names to KiCad
    [PowerAnalyzer.kicad_pcb]
